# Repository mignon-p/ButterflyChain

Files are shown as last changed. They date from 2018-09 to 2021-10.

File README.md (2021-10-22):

# Chainable Butterfly

This repository contains the [KiCad][5] and [Gerber][6] files for a
PCB shaped like a butterfly.  The butterfly contains 18 "NeoPixel"
(WS-2812) LEDs.  The butterflies can be chained together, and
controlled by just about any microcontroller.  However, I specifically
had the [BBC micro:bit][16] in mind, and designed these chainable
butterflies together with my [neo:bit][17] and [feather:bit][18]
boards.

The butterfly design is based on my [butterfly nightlight][19], but I
have removed the microcontroller so that it can be controlled
externally.

* [View schematic](doc/schematic.pdf)
* [View PCB][20]

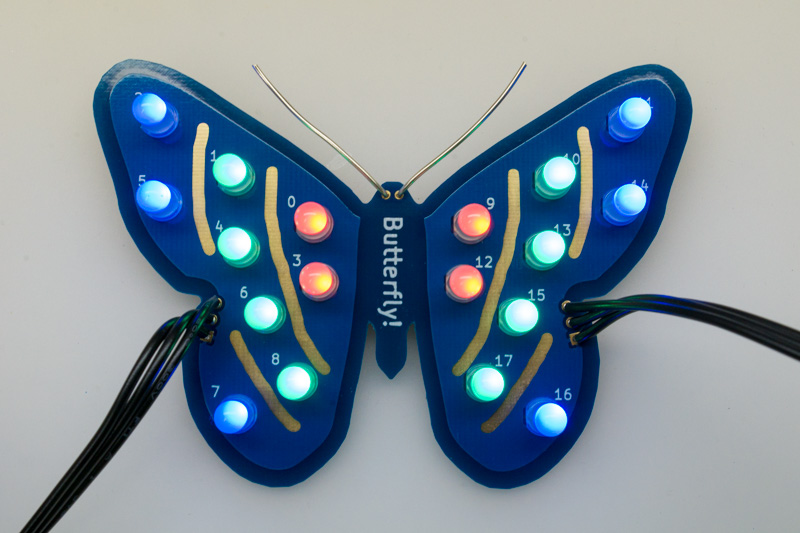
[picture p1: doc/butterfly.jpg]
butterfly board


## Usage

You can use any NeoPixel library on any microcontroller to control the
LEDs on the butterfly.  The silkscreen shows how the LEDs are
numbered.  Note that the NeoPixel butterflies use RGB format, rather
than the more common GRB format.

If you're using the
[micro:bit MakeCode editor](https://makecode.microbit.org/), you can
optionally use my
[butterfly package](https://github.com/ppelleti/pxt-butterfly).  It
makes it easier to control the inner, middle, or outer LEDs on the
butterfly as a group.

My butterfly package is not an "approved" package, so you'll need to
enter its URL specifically.  Expand the "Advanced" box, and choose
"Add Package".  Then enter `https://github.com/ppelleti/pxt-butterfly`
in the search box:

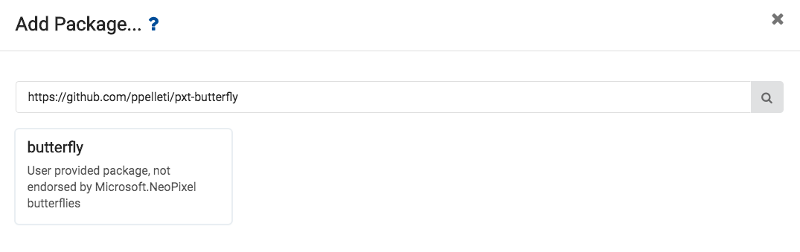
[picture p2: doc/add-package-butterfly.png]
Add Package dialog box


Then just choose the "butterfly" package that appears.

You should then have a "Butterfly" category in your toolbox:

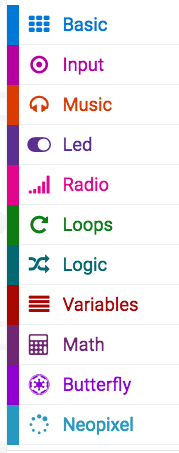
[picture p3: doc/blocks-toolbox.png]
MakeCode toolbox


Now you can use the butterfly blocks:

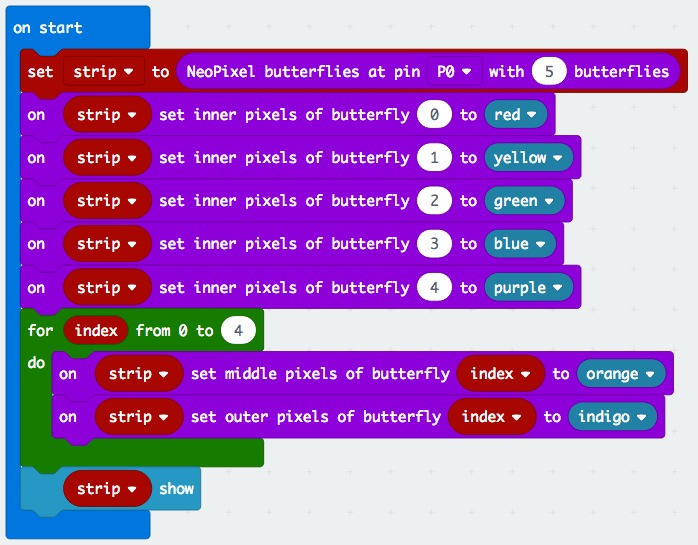
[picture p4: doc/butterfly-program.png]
Butterfly program


Be sure to use the NeoPixel "show" block once you've set your
butterfly colors.

## Bill of Materials

* D1-D18 (qty 18) - 5mm through-hole NeoPixel.  SparkFun part
  no. [COM-12986](https://www.sparkfun.com/products/12986).  Digi-Key
  part no. [1568-1213-ND](https://www.digikey.com/product-detail/en/sparkfun-electronics/COM-12986/1568-1213-ND/5673799).
* C1 (qty 1) - 47µF 1210 capacitor.  Samsung part no. CL32A476MPJNNNE.
  Digi-Key part no. [1276-3380-1-ND](https://www.digikey.com/product-detail/en/samsung-electro-mechanics/CL32A476MPJNNNE/1276-3380-1-ND/3891466).
* J1-J2 (qty 1) - 3-pin JST SM Plug + Receptacle Cable Set.  Adafruit
  part no. [1663](https://www.adafruit.com/product/1663).
* [Bare wire, 20 AWG](https://smile.amazon.com/gp/product/B01BDB8240/).

## Circuit board

This board is big enough that it would be rather expensive to order
from [OSH Park][85], so I would recommend a Chinese fab such as
[Elecrow][86] or [JLCPCB][1].  I chose blue soldermask for my boards,
but red or yellow might work, as well.  I chose the [ENIG][2] finish.

If you're not making any changes to the board, all you need to do is
zip up the files in the `gerber` directory, and upload the zipfile to
Elecrow or JLCPCB.

Note that in the KiCad files and Gerber files, the "front" of the
board is actually the back, and vice-versa. This is because JLCPCB
adds a customer ID number to the front of the board, but I wanted the
number to be on the actual back of the board, where it doesn't disrupt
the esthetics of the butterfly.  (It turns out it's
[possible to specify the location of the customer ID][9], but I hadn't
read that when I first came up with this trick.)

## Assembly

1. Solder the surface-mount capacitor C1 onto the back of the board.

2. Solder the 18 LEDs to the front of the board.  The LED should be
positioned so that the square pad gets one of the longer legs, not one
of the shorter ones.

3. Solder the JST SM plug and receptacle to the J1 and J2 locations.
Be sure to get the polarity right!

4. Create the butterfly's antennae by inserting a length of bare wire
into the holes on the butterfly's head.  (These two holes are
represented by J3 on the schematic.)  It's a tight fit, so friction
may be enough to hold the wire in place, but you can always solder it
to be sure.

## License

This design is licensed under the
[Creative Commons Attribution-ShareAlike 4.0 International license][12].

Some of the footprints in `myLibrary.pretty` are based on footprints
in the [KiCad library][14], which is licensed under the
[KiCad library license][15] (which is now also CC-BY-SA-4.0, with an
exception).

[1]: https://jlcpcb.com/quote
[2]: https://en.wikipedia.org/wiki/Electroless_nickel_immersion_gold
[5]: http://kicad.org/
[6]: https://en.wikipedia.org/wiki/Gerber_format
[9]: https://support.jlcpcb.com/article/28-how-to-remove-the-customer-id-on-the-pcb
[12]: https://creativecommons.org/licenses/by-sa/4.0/
[14]: https://github.com/KiCad/kicad-footprints
[15]: https://forum.kicad.info/t/kicad-library-licensing/7856
[16]: https://microbit.org/
[17]: https://github.com/ppelleti/NeoBit
[18]: https://github.com/ppelleti/FeatherBit
[19]: https://github.com/ppelleti/butterfly-hw
[20]: https://eyrie.io/board/09c10aa2968c4cc28b5949b69b98fd31
[85]: https://oshpark.com/
[86]: https://www.elecrow.com/pcb-manufacturing.html

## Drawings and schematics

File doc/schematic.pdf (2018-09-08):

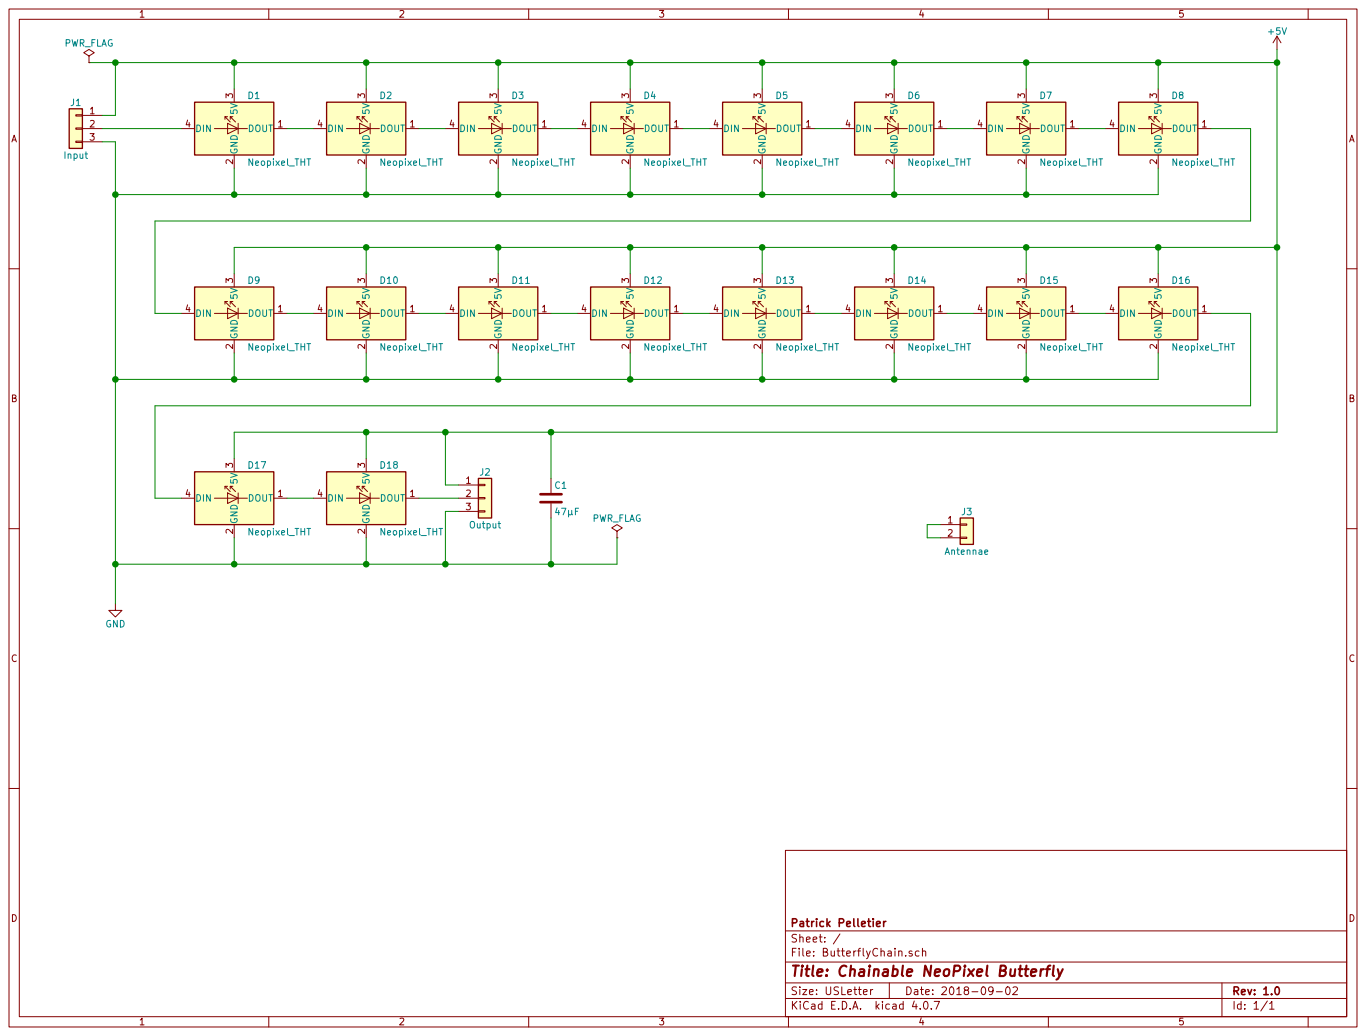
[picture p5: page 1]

File: ButterflyChain.sch Sheet: / Patrick Pelletier

Id: 1/1 Title: Chainable NeoPixel Butterfly

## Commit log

2018-09-03 Remove microcontroller; add connector on each end.
    [ButterflyChain.sch]
2018-09-03 Remove old footprints.
    [ButterflyChain.kicad_pcb]
2018-09-03 Change filled zones.
    [ButterflyChain.kicad_pcb]
2018-09-03 Adjust angle of J1 and J2.
    [ButterflyChain.kicad_pcb]
2018-09-03 Connect data in and out.
    [ButterflyChain.kicad_pcb]
2018-09-03 Fill zones.
    [ButterflyChain.kicad_pcb]
2018-09-03 Change how data tracks are routed.
    [ButterflyChain.kicad_pcb]
2018-09-03 Change silkscreen.
    [ButterflyChain.kicad_pcb]
2018-09-03 Label input/output pins on silkscreen.
    [ButterflyChain.kicad_pcb]
2018-09-03 Label LEDs on silkscreen. (0-based numbering)
    [ButterflyChain.kicad_pcb]
2018-09-03 Remove footprints that are no longer used.
2018-09-03 Add text "Butterfly!" to silkscreen.
    [ButterflyChain.kicad_pcb]
2018-09-04 Regenerate Gerbers.
    [Butterfly-B.SilkS.gbo, Butterfly-F.Cu.gtl, Butterfly-F.SilkS.gto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]
2018-09-08 Update PDF of schematic.
2018-09-16 Revise the PCB ordering section a bit.
2018-09-16 Add links to view schematic and PCB.
2021-10-22 Link to kicad.org
    https://forum.kicad.info/t/warning-avoid-all-links-to-kicad-pcb-org-use-kicad-org/31521
